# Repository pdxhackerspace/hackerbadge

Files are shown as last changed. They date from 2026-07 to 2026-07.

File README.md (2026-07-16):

# PDX Hackerspace Hackerbadge





The unofficial badge of PDX Hackerspace.

- 37 WS2812B addressable RGB LEDs
- SeeedStudio Xiao ESP32-S3 (8MB PSRAM/8MB flash)
- LSM6DSO accelerometer/gyroscope
- 18650 LiPO battery
- Qwiic/STEMMA QT I2C connector

Though we've specced this for a Xiao ESP32-S3, this should work with any Xiao board with a compatible pinout. If the board doesn't support LiPO battery charging then obviously it will only work when plugged into USB.

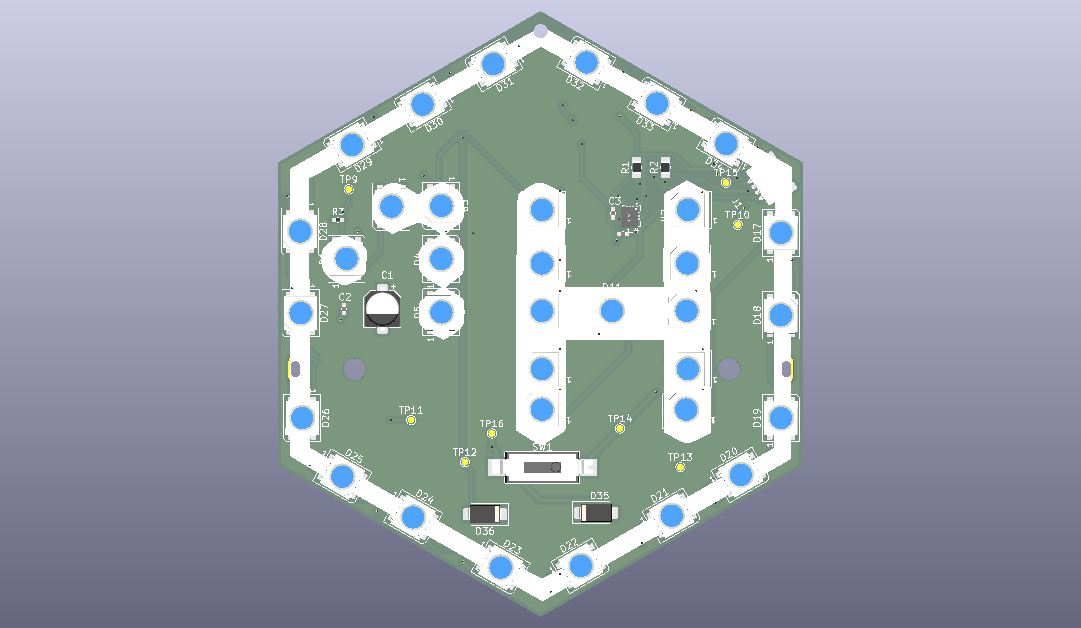
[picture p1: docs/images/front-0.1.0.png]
front
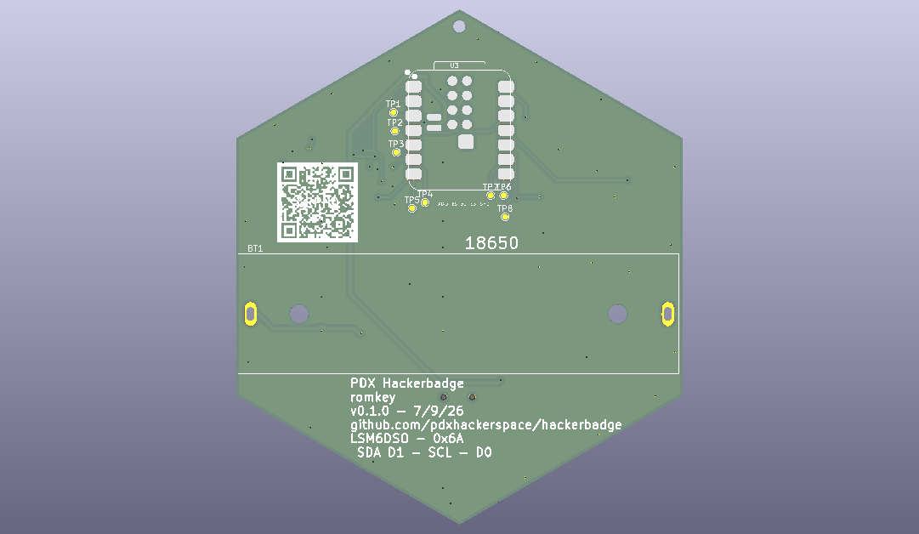
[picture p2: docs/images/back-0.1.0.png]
back
 

## LED power

LEDs are powered either through the VBUS or VBAT, avoiding straining the board's 3.3V regulator and providing more voltage to them for more reliable operation. We use two SS23 Schottky diodes to OR the power sources together and avoid feeding back into one another.

## LED control

Xiao ESP32-S3 D10 controls the LEDs.

## Qwiic/STEMMA QT/I2C

SDA - D1
SCL - D0

## Accelerometer/Gyroscope

The board includes an LSM6DSO accelerometer/gyroscope for fancy effects, or you can just ignore it. I2C address 0x6A.

## Firmware

Hardware self-test sketches live under `firmware/test/`. They cycle LED colors/patterns and exercise the LSM6DSO. Production-style options (WLED, ESPHome, CircuitPython) are below.

### WLED

1. Hold the Xiao **BOOT** button, plug in USB, then release BOOT so the board is in download mode.
2. Open the [WLED web installer](https://install.wled.me/) (or [alternate installer](https://wled-install.github.io/)) in Chrome/Edge.
3. Choose an **ESP32-S3** build that matches this board: **8MB flash** and **PSRAM** (OPI / `qio_opi` style binaries are the usual fit for the Xiao ESP32-S3). Flash it.
4. Join Wi‑Fi AP `WLED-AP` (password `wled1234`) and open [http://4.3.2.1](http://4.3.2.1).
5. **Config → LED Preferences** and set:
   - LED count / length: **37**
   - GPIO / data pin: **9** (Xiao **D10**)
   - LED type: **WS281x**
   - Color order: **GRB**
6. Save, then optionally configure your home Wi‑Fi under **Config → WiFi Setup**.

Stock WLED does not use the LSM6DSO.

**Docker Compose** (build a badge-tuned binary with GPIO 9 / 37 LEDs preconfigured):

```bash
cd firmware/wled
docker compose run --rm build
```

Firmware ends up under `firmware/wled/build/`. Flash with the web installer, `esptool`, or:

```bash
DEVICE=/dev/ttyACM0 docker compose run --rm --device=$DEVICE build upload
```

If the OPI-PSRAM build won’t boot, try `PIO_ENV=hackerbadge_qspi docker compose run --rm build`. See also [Compiling WLED](https://kno.wled.ge/advanced/compiling-wled/).

### ESPHome

Test config: `firmware/test/esphome/badge_test.yaml`

Requires an ESPHome release with the `motion` / `lsm6ds` platform. After flash, the badge cycles LED effects and logs IMU samples over serial. It also brings up AP `Hackerbadge-Test` (password `hackerspace`); open [http://192.168.4.1](http://192.168.4.1) for the web UI.

**Docker Compose** (dashboard on [http://localhost:6052](http://localhost:6052)):

```bash
cd firmware/test/esphome
docker compose up
```

Compile only, or compile and flash over USB:

```bash
docker compose run --rm esphome compile badge_test.yaml
DEVICE=/dev/ttyACM0 docker compose run --rm --device=$DEVICE esphome run badge_test.yaml
```

Without Docker: `esphome run firmware/test/esphome/badge_test.yaml`

### CircuitPython

Test program: `firmware/test/circuitpython/code.py`

1. Install [CircuitPython for Seeed Xiao ESP32-S3](https://circuitpython.org/board/seeed_xiao_esp32s3/).
2. From the [Adafruit library bundle](https://circuitpython.org/libraries), copy into `CIRCUITPY/lib/`:
   - `neopixel.mpy` (and `adafruit_pixelbuf.mpy` if present in your bundle)
   - `adafruit_lsm6ds/`
   - `adafruit_bus_device/`
   - `adafruit_register/`
3. Copy `firmware/test/circuitpython/code.py` to `CIRCUITPY/code.py`.

Watch the serial REPL for IMU logs while LEDs cycle.

### Arduino

Test sketch: `firmware/test/arduino/badge_test/badge_test.ino`

**Docker Compose** (Arduino CLI build; artifacts in `firmware/test/arduino/build/`):

```bash
cd firmware/test/arduino
docker compose run --rm build
```

Upload over USB after a successful compile:

```bash
DEVICE=/dev/ttyACM0 docker compose run --rm --device=$DEVICE build upload
```

Without Docker:

1. In Arduino IDE, install board support for **Seeed XIAO ESP32S3**.
2. Install libraries: **FastLED**, **Adafruit LSM6DS** (pulls in BusIO and Unified Sensor).
3. Open the `badge_test` sketch, select the Xiao ESP32S3 board/port, and upload.

Serial Monitor at 115200 baud shows effect names and IMU readings.

## Assembly

The badge comes prebuilt except for the Xiao and the battery holder, which are mounted on the back of the board. We suggest soldering on the Xiao using solder paste and a hot air gun. You're unlikely to make a solder plate work due to the components on the front of the board. The most difficult part will be the battery connectors under the board.

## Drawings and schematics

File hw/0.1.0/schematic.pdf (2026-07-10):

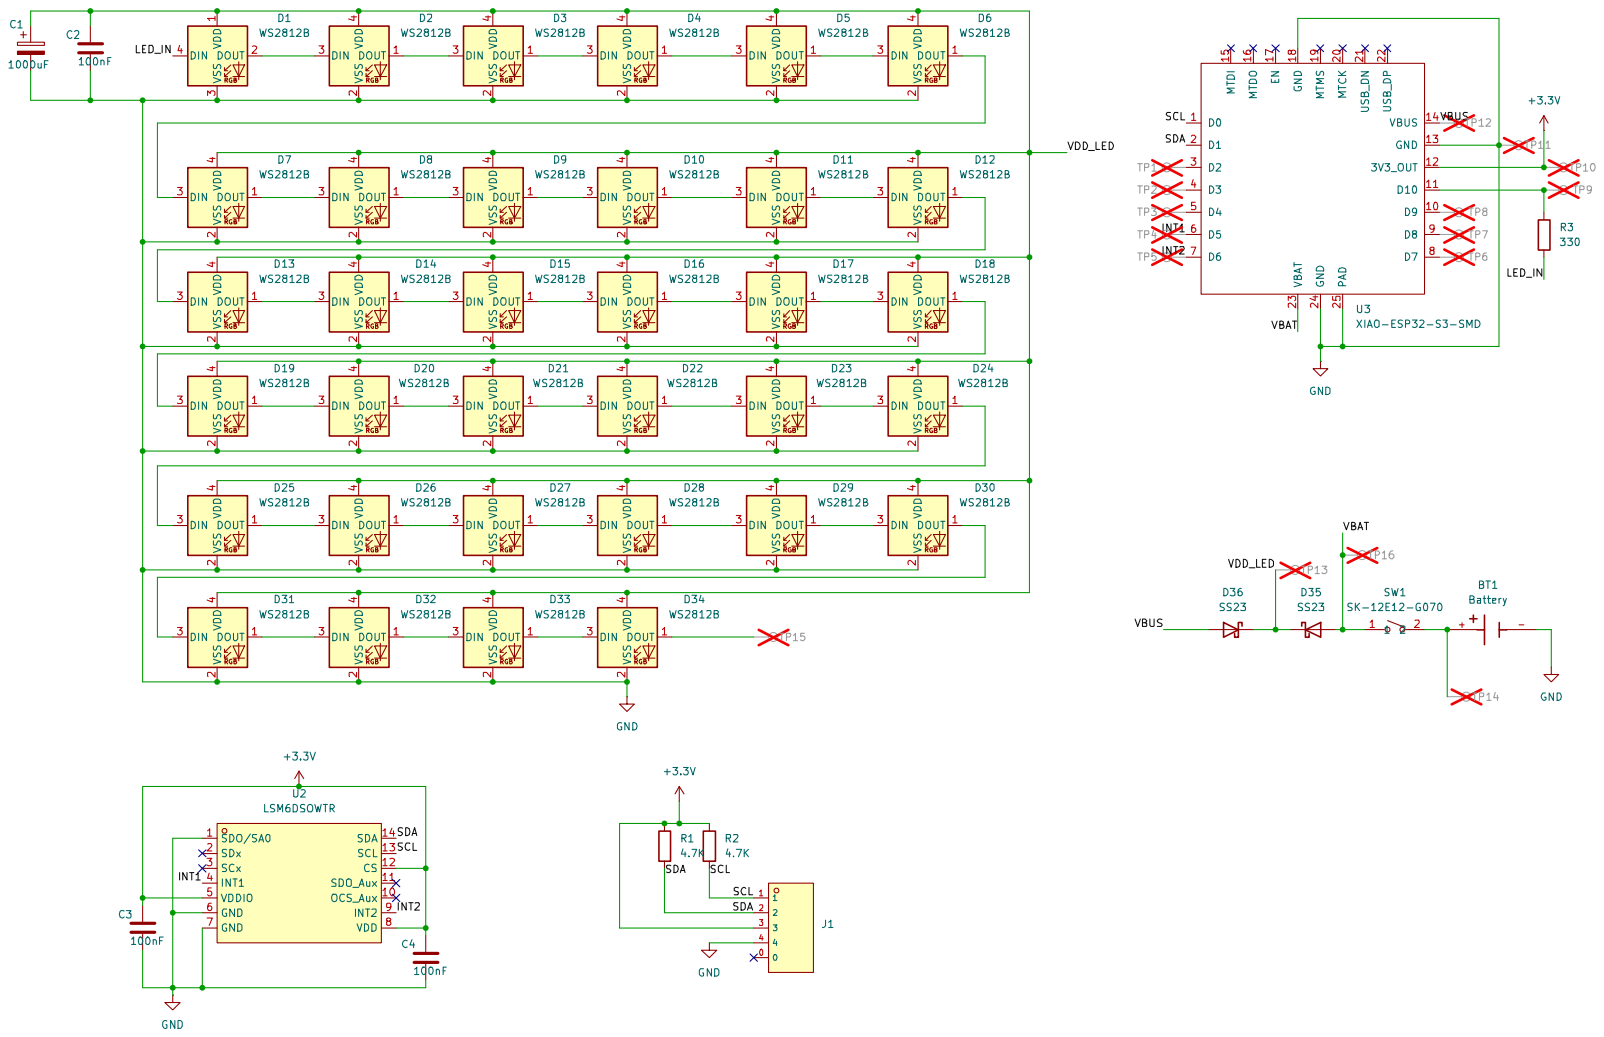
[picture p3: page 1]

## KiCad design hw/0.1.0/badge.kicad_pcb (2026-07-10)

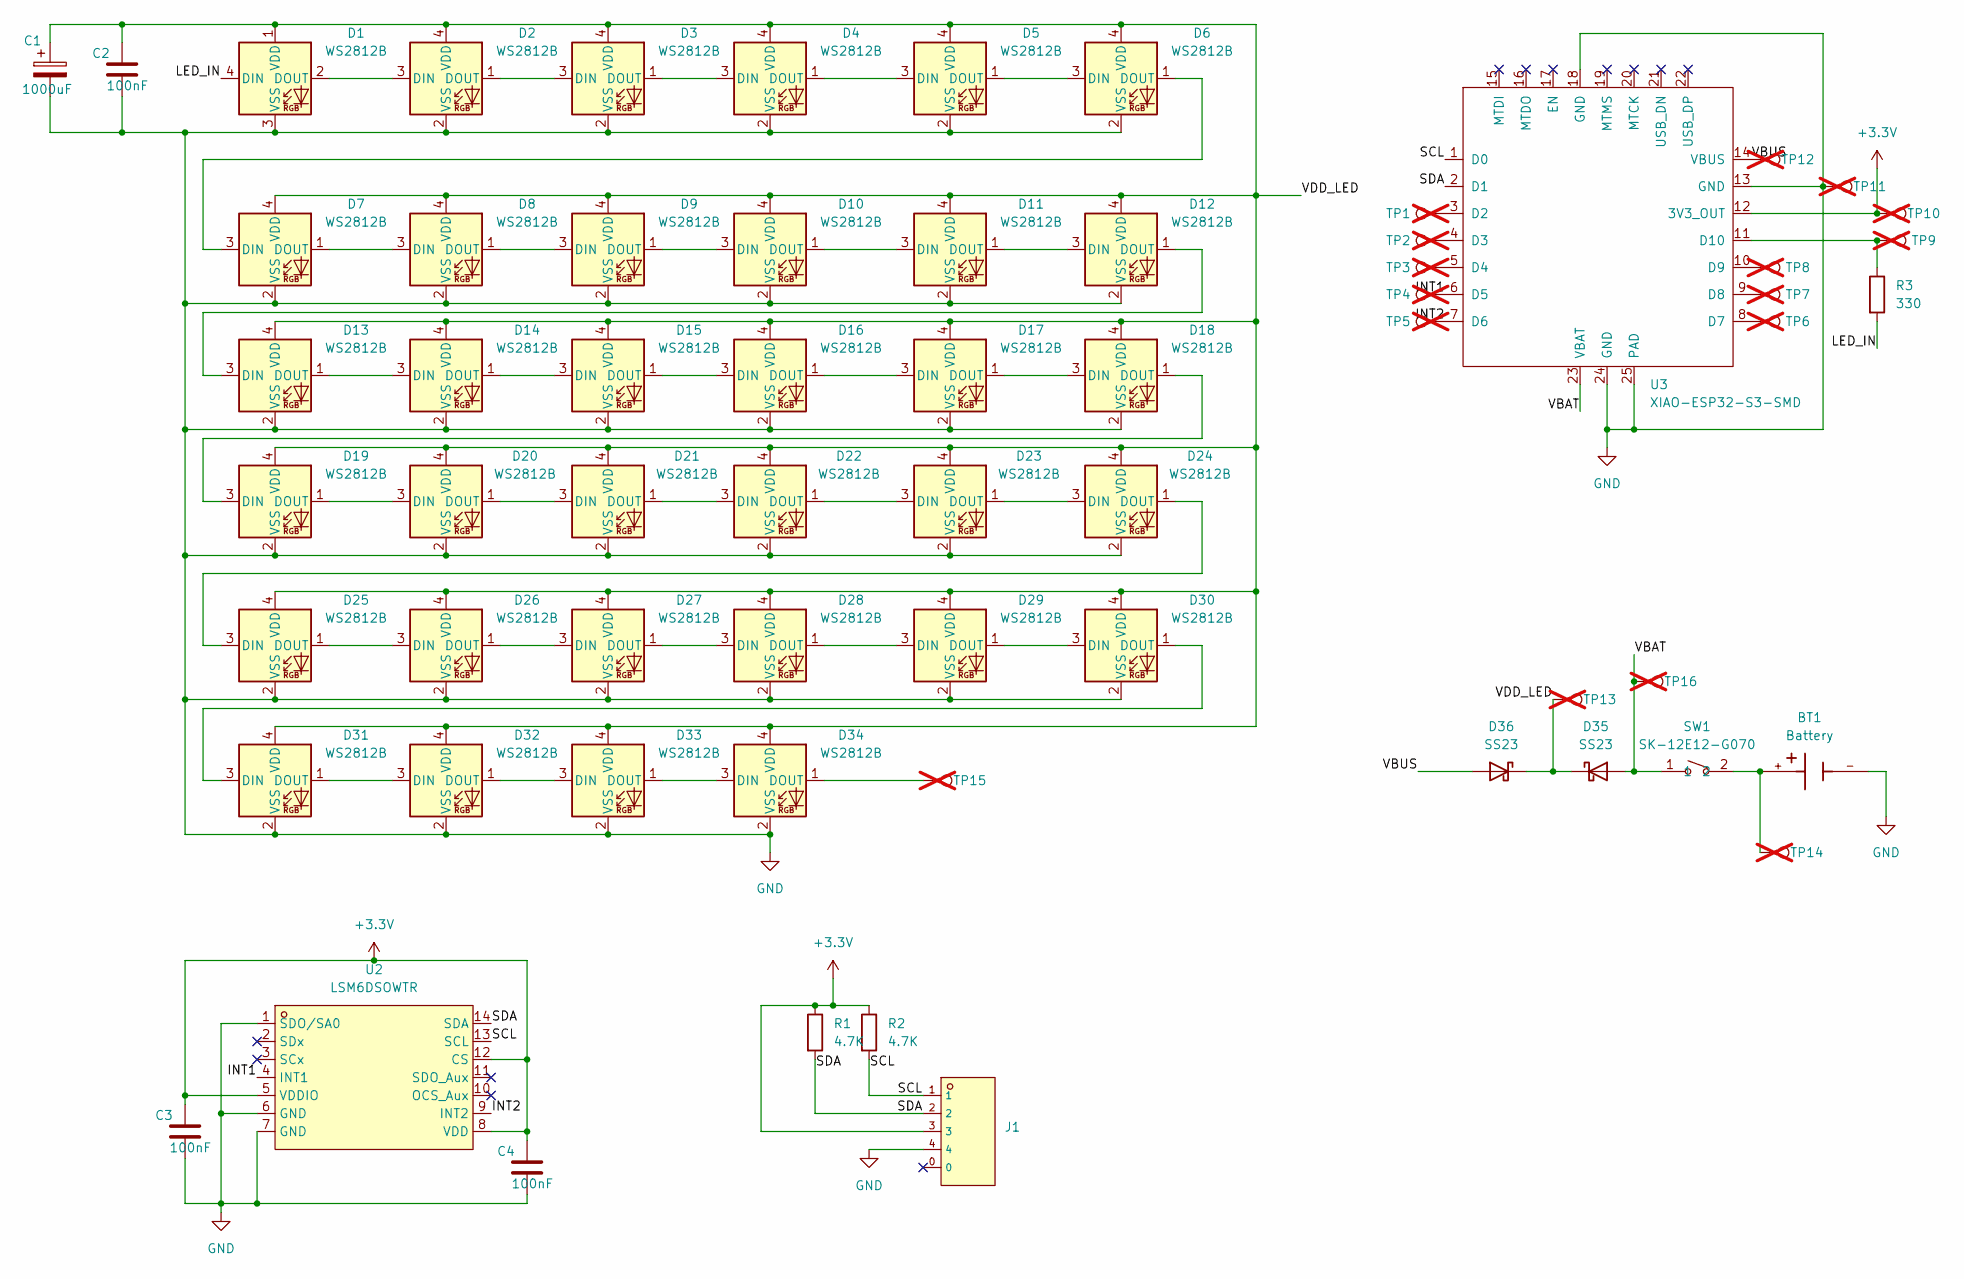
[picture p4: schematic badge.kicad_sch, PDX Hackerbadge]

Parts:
BT1: Battery; BAT_BK-18650-PC2; PARTREV F
C1: 1000uF; CP_Elec_5x5.4; MPN C3337
C2, C3, C4: 100nF; C_0402_1005Metric_Pad0.74x0.62mm_HandSolder; MPN C1523
D1, D2, D3, D4, D5, D6, D7, D8, D9, D10, D11, D12, D13, D14, D15, D16, D17, D18, D19, D20, D21, D22, D23, D24, D25, D26, D27, D28, D29, D30, D31, D32, D33, D34: WS2812B; LED_WS2812B_PLCC4_5.0x5.0mm_P3.2mm; MPN C52917433
D35, D36: SS23; D_SMA; MPN C232851
J1: CONN-SMD_4P-P1.00_SM04B-SRSS-TB-LF-SN; MPN C160404; LCSC C160390
R1, R2: 4.7K; R_0805_2012Metric_Pad1.20x1.40mm_HandSolder; MPN C105427
R3: 330; R_0402_1005Metric_Pad0.72x0.64mm_HandSolder; MPN C25104
SW1: SK-12E12-G070; SW-TH_MS-12D08G3.5; LCSC Part C2939255
TP1: D2; TestPoint_Pad_D1.0mm; not fitted
TP2: D3; TestPoint_Pad_D1.0mm; not fitted
TP3: D4; TestPoint_Pad_D1.0mm; not fitted
TP4: D5; TestPoint_Pad_D1.0mm; not fitted
TP5: INT2; TestPoint_Pad_D1.0mm; not fitted
TP6: D7; TestPoint_Pad_D1.0mm; not fitted
TP7: D8; TestPoint_Pad_D1.0mm; not fitted
TP8: D9; TestPoint_Pad_D1.0mm; not fitted
TP9: D10; TestPoint_Pad_D1.0mm; not fitted
TP10: 3V3; TestPoint_Pad_D1.0mm; not fitted
TP11: GND; TestPoint_Pad_D1.0mm; not fitted
TP12: VBUS; TestPoint_Pad_D1.0mm; not fitted
TP13: VDD_LED; TestPoint_Pad_D1.0mm; not fitted
TP14: RAWBAT; TestPoint_Pad_D1.0mm; not fitted
TP15: D34 DOUT; TestPoint_Pad_D1.0mm; not fitted
TP16: VBAT; TestPoint_Pad_D1.0mm; not fitted
U2: LSM6DSOWTR; LGA-14L_L3.0-W2.5-P0.50-TL; MPN C2829074; LCSC Part C2829074
U3: XIAO-ESP32-S3-SMD

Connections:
+3.3V: C3.1, C4.1, J1.3, R1.1, R2.1, TP10.1 (1_1), U2.5 (VDDIO), U2.8 (VDD), U2.12 (CS), U3.12 (3V3_OUT)
/INT1: TP4.1 (1_1), U2.4 (INT1), U3.6 (D5)
/INT2: TP5.1 (1_1), U2.9 (INT2), U3.7 (D6)
/LED_IN: D1.4 (DIN), R3.2
/SCL: J1.1, R2.2, U2.13 (SCL), U3.1 (D0)
/SDA: J1.2, R1.2, U2.14 (SDA), U3.2 (D1)
/VBAT: D35.2 (A), SW1.1, TP16.1 (1_1), U3.23 (VBAT)
/VBUS: D36.2 (A), TP12.1 (1_1), U3.14 (VBUS)
/VDD_LED: C1.1, C2.1, D1.1 (VDD), D2.4 (VDD), D3.4 (VDD), D4.4 (VDD), D5.4 (VDD), D6.4 (VDD), D7.4 (VDD), D8.4 (VDD), D9.4 (VDD), D10.4 (VDD), D11.4 (VDD), D12.4 (VDD), D13.4 (VDD), D14.4 (VDD), D15.4 (VDD), D16.4 (VDD), D17.4 (VDD), D18.4 (VDD), D19.4 (VDD), D20.4 (VDD), D21.4 (VDD), D22.4 (VDD), D23.4 (VDD), D24.4 (VDD), D25.4 (VDD), D26.4 (VDD), D27.4 (VDD), D28.4 (VDD), D29.4 (VDD), D30.4 (VDD), D31.4 (VDD), D32.4 (VDD), D33.4 (VDD), D34.4 (VDD), D35.1 (K), D36.1 (K), TP13.1 (1_1)
GND: BT1.-, C1.2, C2.2, C3.2, C4.2, D1.3 (VSS), D2.2 (VSS), D3.2 (VSS), D4.2 (VSS), D5.2 (VSS), D6.2 (VSS), D7.2 (VSS), D8.2 (VSS), D9.2 (VSS), D10.2 (VSS), D11.2 (VSS), D12.2 (VSS), D13.2 (VSS), D14.2 (VSS), D15.2 (VSS), D16.2 (VSS), D17.2 (VSS), D18.2 (VSS), D19.2 (VSS), D20.2 (VSS), D21.2 (VSS), D22.2 (VSS), D23.2 (VSS), D24.2 (VSS), D25.2 (VSS), D26.2 (VSS), D27.2 (VSS), D28.2 (VSS), D29.2 (VSS), D30.2 (VSS), D31.2 (VSS), D32.2 (VSS), D33.2 (VSS), D34.2 (VSS), J1.4, TP11.1 (1_1), U2.1 (SDO/SA0), U2.6 (GND), U2.7 (GND), U3.13 (GND), U3.18 (GND), U3.24 (GND), U3.25 (PAD)
unnamed: BT1.+, SW1.2, TP14.1 (1_1)
unnamed: D1.2 (DOUT), D2.3 (DIN)
unnamed: D2.1 (DOUT), D3.3 (DIN)
unnamed: D3.1 (DOUT), D4.3 (DIN)
unnamed: D4.1 (DOUT), D5.3 (DIN)
unnamed: D5.1 (DOUT), D6.3 (DIN)
unnamed: D6.1 (DOUT), D7.3 (DIN)
unnamed: D7.1 (DOUT), D8.3 (DIN)
unnamed: D8.1 (DOUT), D9.3 (DIN)
unnamed: D9.1 (DOUT), D10.3 (DIN)
unnamed: D10.1 (DOUT), D11.3 (DIN)
unnamed: D11.1 (DOUT), D12.3 (DIN)
unnamed: D12.1 (DOUT), D13.3 (DIN)
unnamed: D13.1 (DOUT), D14.3 (DIN)
unnamed: D14.1 (DOUT), D15.3 (DIN)
unnamed: D15.1 (DOUT), D16.3 (DIN)
unnamed: D16.1 (DOUT), D17.3 (DIN)
unnamed: D17.1 (DOUT), D18.3 (DIN)
unnamed: D18.1 (DOUT), D19.3 (DIN)
unnamed: D19.1 (DOUT), D20.3 (DIN)
unnamed: D20.1 (DOUT), D21.3 (DIN)
unnamed: D21.1 (DOUT), D22.3 (DIN)
unnamed: D22.1 (DOUT), D23.3 (DIN)
unnamed: D23.1 (DOUT), D24.3 (DIN)
unnamed: D24.1 (DOUT), D25.3 (DIN)
unnamed: D25.1 (DOUT), D26.3 (DIN)
unnamed: D26.1 (DOUT), D27.3 (DIN)
unnamed: D27.1 (DOUT), D28.3 (DIN)
unnamed: D28.1 (DOUT), D29.3 (DIN)
unnamed: D29.1 (DOUT), D30.3 (DIN)
unnamed: D30.1 (DOUT), D31.3 (DIN)
unnamed: D31.1 (DOUT), D32.3 (DIN)
unnamed: D32.1 (DOUT), D33.3 (DIN)
unnamed: D33.1 (DOUT), D34.3 (DIN)
unnamed: D34.1 (DOUT), TP15.1 (1_1)
unnamed: TP1.1 (1_1), U3.3 (D2)
unnamed: TP2.1 (1_1), U3.4 (D3)
unnamed: TP3.1 (1_1), U3.5 (D4)
unnamed: TP6.1 (1_1), U3.8 (D7)
unnamed: TP7.1 (1_1), U3.9 (D8)
unnamed: TP8.1 (1_1), U3.10 (D9)
unnamed: R3.1, TP9.1 (1_1), U3.11 (D10)

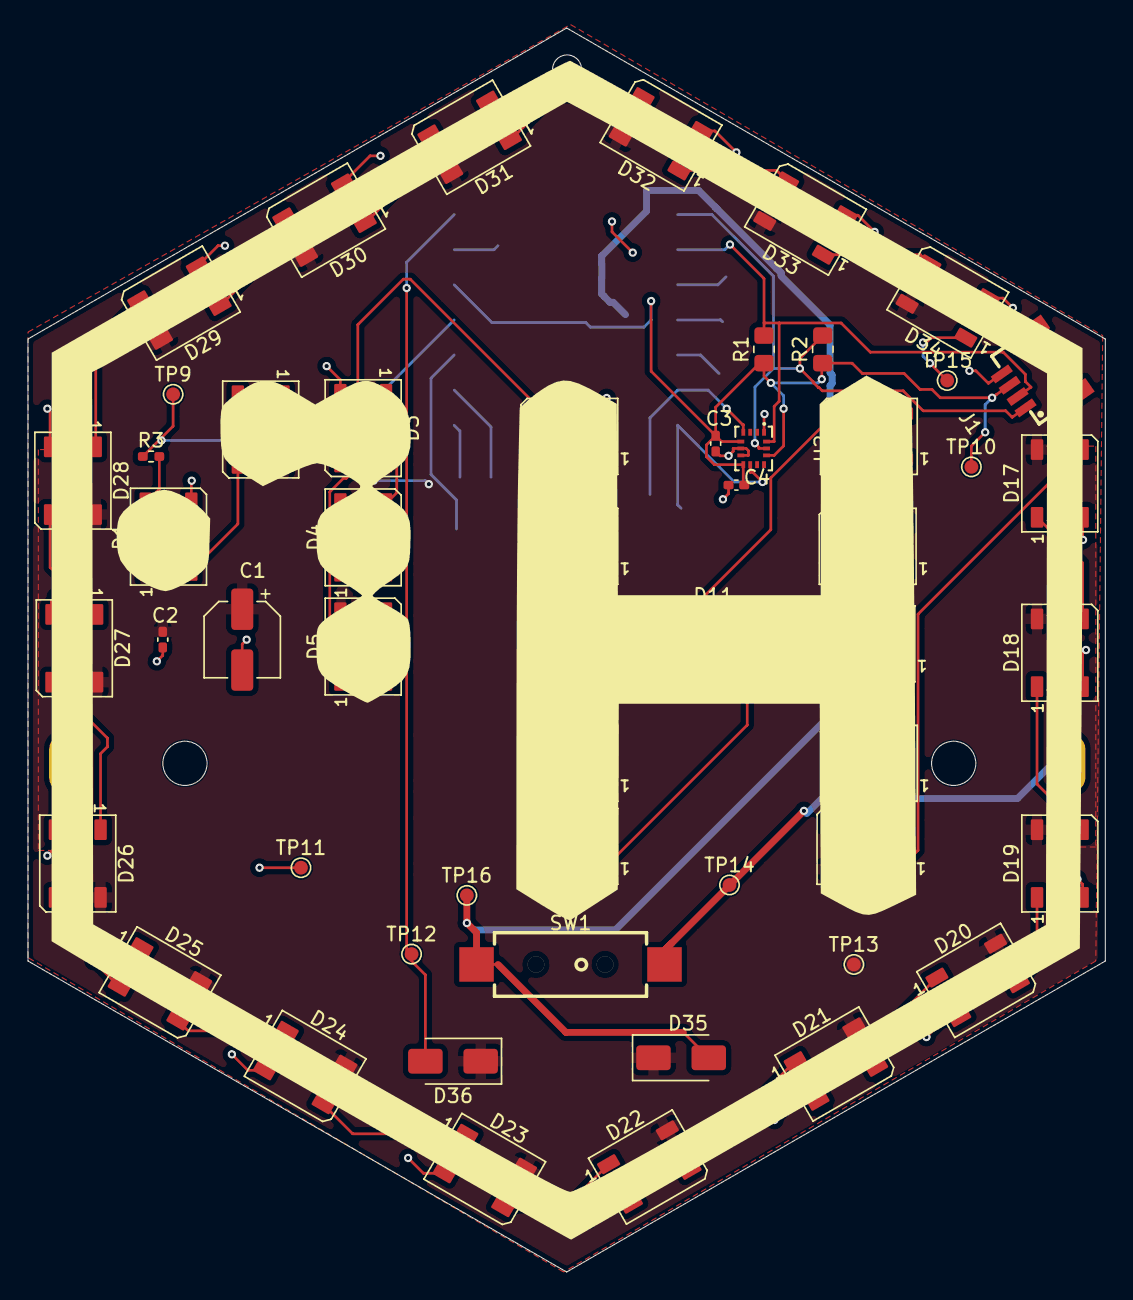
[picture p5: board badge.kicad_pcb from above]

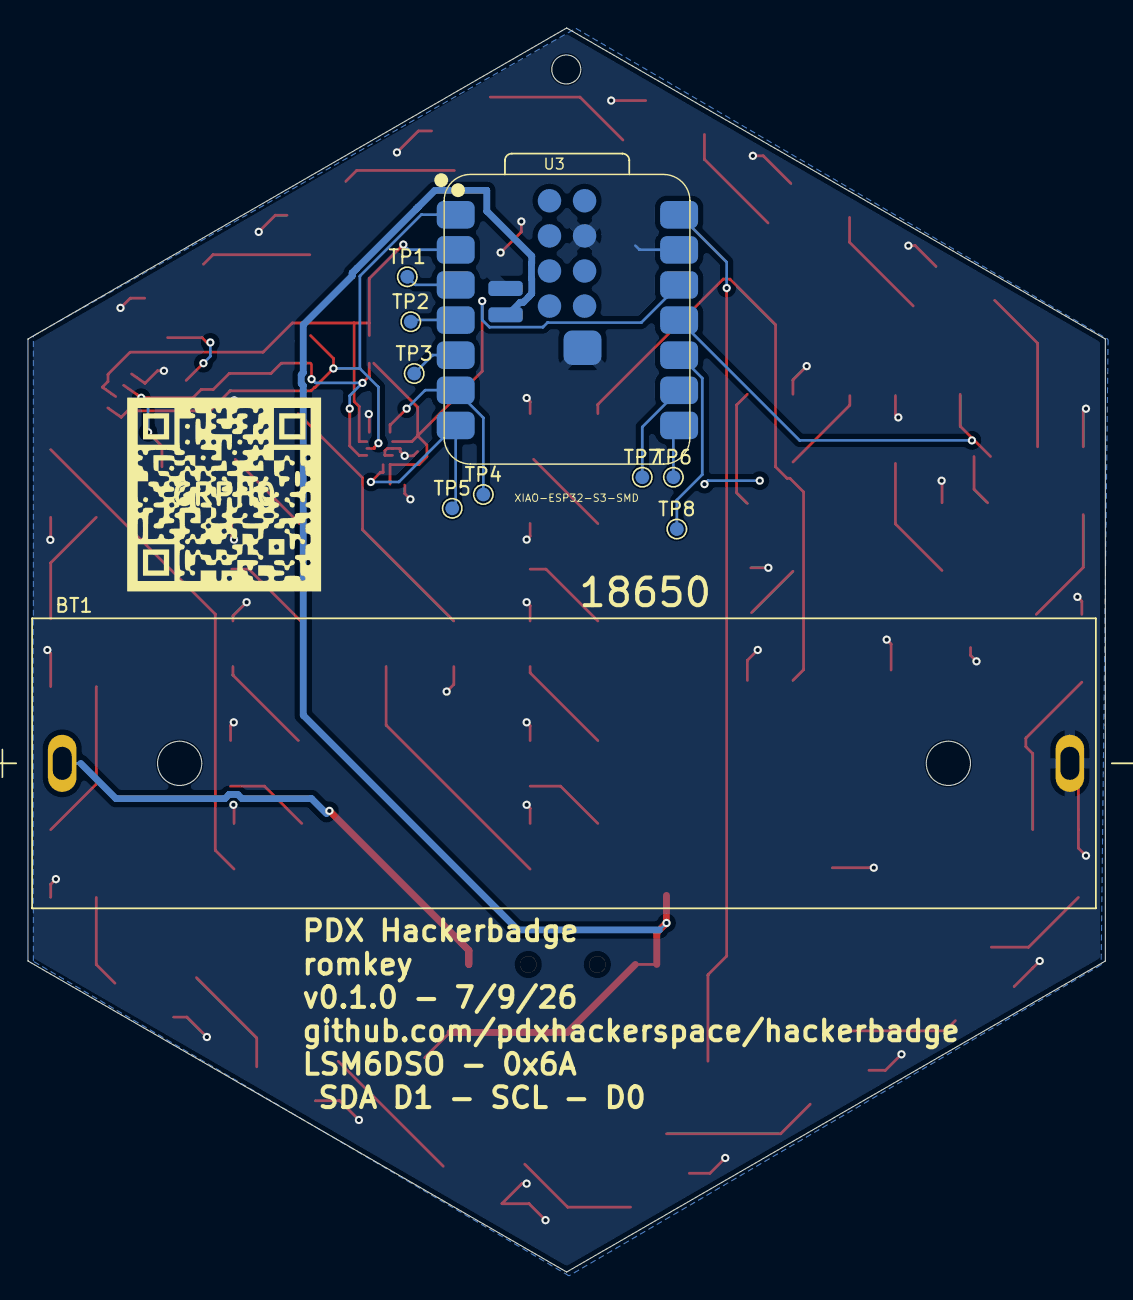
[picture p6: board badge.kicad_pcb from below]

Board: 2 copper layers, 77.9 x 90.0 mm, 66 parts (11 on the bottom side), 52 nets.

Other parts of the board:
GRPH0: LOGO
MNT0: MountingHole_2.1mm

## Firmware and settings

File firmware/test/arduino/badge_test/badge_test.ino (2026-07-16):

/*
 * PDX Hackerspace Hackerbadge — Arduino / FastLED hardware test
 *
 * Exercises the 37 WS2812B LEDs (colors + patterns) and the LSM6DSO IMU.
 *
 * Pinout (Seeed Xiao ESP32-S3):
 *   LED data  D10 = GPIO9
 *   I2C SDA   D1  = GPIO2
 *   I2C SCL   D0  = GPIO1
 *   LSM6DSO   0x6A
 *
 * Board:  Seeed XIAO ESP32S3
 * Libraries (Library Manager):
 *   - FastLED
 *   - Adafruit LSM6DS
 *   - Adafruit Unified Sensor  (dependency)
 *   - Adafruit BusIO           (dependency)
 *
 * After boot the badge cycles solid colors and patterns. Serial logs print
 * accel/gyro samples. The Accel Tilt effect maps orientation to LEDs.
 */

#include <Wire.h>
#include <FastLED.h>
#include <Adafruit_LSM6DSOX.h>
#include <Adafruit_Sensor.h>
#include <math.h>

#if defined(ARDUINO_XIAO_ESP32S3) || defined(ARDUINO_SEEED_XIAO_ESP32S3)
#define LED_DATA_PIN D10
#define I2C_SDA_PIN D1
#define I2C_SCL_PIN D0
#else
// Xiao ESP32-S3 GPIO map when using a generic ESP32-S3 board package
#define LED_DATA_PIN 9
#define I2C_SDA_PIN 2
#define I2C_SCL_PIN 1
#endif

#define NUM_LEDS 37
#define BRIGHTNESS 102  // ~40% of 255
#define EFFECT_MS 8000
#define IMU_LOG_MS 2000
#define FRAME_MS 40

CRGB leds[NUM_LEDS];
Adafruit_LSM6DSOX imu;
bool imuOk = false;
uint32_t lastImuLogMs = 0;

static float clampf(float v, float lo, float hi) {
  if (v < lo) return lo;
  if (v > hi) return hi;
  return v;
}

static void maybeLogImu(bool force = false) {
  uint32_t now = millis();
  if (!force && (now - lastImuLogMs) < IMU_LOG_MS) {
    return;
  }
  lastImuLogMs = now;

  if (!imuOk) {
    Serial.println(F("IMU: no accelerometer data (check I2C 0x6A)"));
    return;
  }

  sensors_event_t accel, gyro, temp;
  imu.getEvent(&accel, &gyro, &temp);

  Serial.printf(
      "IMU accel m/s2=(%.2f, %.2f, %.2f) gyro dps=(%.1f, %.1f, %.1f)\n",
      accel.acceleration.x, accel.acceleration.y, accel.acceleration.z,
      gyro.gyro.x * RAD_TO_DEG, gyro.gyro.y * RAD_TO_DEG,
      gyro.gyro.z * RAD_TO_DEG);
}

static void solid(const CRGB &color, uint32_t durationMs) {
  fill_solid(leds, NUM_LEDS, color);
  FastLED.show();
  uint32_t end = millis() + durationMs;
  while (millis() < end) {
    maybeLogImu();
    delay(50);
  }
}

static void rainbow(uint32_t durationMs) {
  uint32_t start = millis();
  uint8_t offset = 0;
  while (millis() - start < durationMs) {
    for (int i = 0; i < NUM_LEDS; i++) {
      leds[i] = CHSV(offset + (i * 255 / NUM_LEDS), 255, 255);
    }
    FastLED.show();
    offset += 4;
    maybeLogImu();
    delay(FRAME_MS);
  }
}

static void colorWipe(uint32_t durationMs) {
  const CRGB colors[] = {
      CRGB::Red, CRGB::Green, CRGB::Blue, CRGB::White,
  };
  uint32_t start = millis();
  while (millis() - start < durationMs) {
    for (CRGB color : colors) {
      for (int i = 0; i < NUM_LEDS; i++) {
        if (millis() - start >= durationMs) {
          return;
        }
        leds[i] = color;
        FastLED.show();
        maybeLogImu();
        delay(40);
      }
    }
  }
}

static void scan(uint32_t durationMs) {
  uint32_t start = millis();
  int pos = 0;
  int direction = 1;
  const int width = 3;
  while (millis() - start < durationMs) {
    fill_solid(leds, NUM_LEDS, CRGB::Black);
    for (int w = 0; w < width; w++) {
      int idx = pos + w;
      if (idx >= 0 && idx < NUM_LEDS) {
        leds[idx] = CRGB(0, 180, 255);
      }
    }
    FastLED.show();
    pos += direction;
    if (pos <= 0) {
      pos = 0;
      direction = 1;
    } else if (pos >= NUM_LEDS - width) {
      pos = NUM_LEDS - width;
      direction = -1;
    }
    maybeLogImu();
    delay(FRAME_MS);
  }
}

static void twinkle(uint32_t durationMs, bool randomColor) {
  uint32_t start = millis();
  uint8_t levels[NUM_LEDS] = {0};
  CRGB colors[NUM_LEDS];
  while (millis() - start < durationMs) {
    for (int i = 0; i < NUM_LEDS; i++) {
      if (levels[i] == 0 && random8() < 20) {  // ~8% of 255
        levels[i] = 255;
        colors[i] = randomColor ? CRGB(CHSV(random8(), 255, 255)) : CRGB::White;
      }
      if (levels[i] > 0) {
        leds[i] = colors[i];
        leds[i].nscale8(levels[i]);
        levels[i] = (levels[i] > 12) ? (levels[i] - 12) : 0;
      } else {
        leds[i] = CRGB::Black;
      }
    }
    FastLED.show();
    maybeLogImu();
    delay(FRAME_MS);
  }
}

static void fireworks(uint32_t durationMs) {
  uint32_t start = millis();
  uint8_t levels[NUM_LEDS] = {0};
  CRGB colors[NUM_LEDS];
  while (millis() - start < durationMs) {
    if (random8() < 30) {  // ~12%
      int i = random8(NUM_LEDS);
      levels[i] = 255;
      colors[i] = CHSV(random8(), 255, 255);
    }
    for (int i = 0; i < NUM_LEDS; i++) {
      if (levels[i] > 0) {
        leds[i] = colors[i];
        leds[i].nscale8(levels[i]);
        levels[i] = (levels[i] > 8) ? (levels[i] - 8) : 0;
      } else {
        leds[i] = CRGB::Black;
      }
    }
    FastLED.show();
    maybeLogImu();
    delay(FRAME_MS);
  }
}

static void accelTilt(uint32_t durationMs) {
  uint32_t start = millis();
  while (millis() - start < durationMs) {
    maybeLogImu();
    if (!imuOk) {
      fill_solid(leds, NUM_LEDS, CRGB(40, 0, 0));
      FastLED.show();
      delay(200);
      continue;
    }

    sensors_event_t accel, gyro, temp;
    imu.getEvent(&accel, &gyro, &temp);
    float ax = accel.acceleration.x;
    float ay = accel.acceleration.y;
    float az = accel.acceleration.z;

    float pitch = atan2f(-ax, sqrtf(ay * ay + az * az)) * RAD_TO_DEG;
    float roll = atan2f(ay, az) * RAD_TO_DEG;
    float pr = clampf((pitch + 45.0f) / 90.0f, 0.0f, 1.0f);
    float rr = clampf((roll + 45.0f) / 90.0f, 0.0f, 1.0f);

    uint8_t red = (uint8_t)(pr * 255.0f);
    uint8_t green = (uint8_t)(rr * 255.0f);
    uint8_t blue = (uint8_t)((1.0f - fabsf(pr - 0.5f) * 2.0f) * 80.0f);

    fill_solid(leds, NUM_LEDS, CRGB(red / 4, green / 4, blue / 4));
    int idx = (int)(rr * (NUM_LEDS - 1));
    leds[idx] = CRGB(red, green, 255);
    FastLED.show();
    delay(FRAME_MS);
  }
}

struct Effect {
  const char *name;
  void (*run)(uint32_t durationMs);
};

// Wrappers so twinkle variants fit the Effect table
static void twinkleWhite(uint32_t ms) { twinkle(ms, false); }
static void twinkleRandom(uint32_t ms) { twinkle(ms, true); }
static void solidRed(uint32_t ms) { solid(CRGB::Red, ms); }
static void solidGreen(uint32_t ms) { solid(CRGB::Green, ms); }
static void solidBlue(uint32_t ms) { solid(CRGB::Blue, ms); }
static void solidWhite(uint32_t ms) { solid(CRGB::White, ms); }
static void solidCyan(uint32_t ms) { solid(CRGB::Cyan, ms); }
static void solidMagenta(uint32_t ms) { solid(CRGB::Magenta, ms); }
static void solidYellow(uint32_t ms) { solid(CRGB::Yellow, ms); }

static const Effect EFFECTS[] = {
    {"Solid Red", solidRed},
    {"Solid Green", solidGreen},
    {"Solid Blue", solidBlue},
    {"Solid White", solidWhite},
    {"Solid Cyan", solidCyan},
    {"Solid Magenta", solidMagenta},
    {"Solid Yellow", solidYellow},
    {"Rainbow", rainbow},
    {"Color Wipe", colorWipe},
    {"Scan", scan},
    {"Twinkle", twinkleWhite},
    {"Random Twinkle", twinkleRandom},
    {"Fireworks", fireworks},
    {"Accel Tilt", accelTilt},
};

void setup() {
  Serial.begin(115200);
  delay(500);
  Serial.println(F("Hackerbadge test starting — LED pattern loop + IMU"));

  FastLED.addLeds<WS2812B, LED_DATA_PIN, GRB>(leds, NUM_LEDS);
  FastLED.setBrightness(BRIGHTNESS);
  FastLED.clear(true);

  // Badge I2C is on D0/D1, not the Xiao default SDA/SCL pads.
  Wire.begin(I2C_SDA_PIN, I2C_SCL_PIN);

  imuOk = imu.begin_I2C(0x6A, &Wire);
  if (imuOk) {
    imu.setAccelRange(LSM6DS_ACCEL_RANGE_4_G);
    imu.setGyroRange(LSM6DS_GYRO_RANGE_2000_DPS);
    imu.setAccelDataRate(LSM6DS_RATE_104_HZ);
    imu.setGyroDataRate(LSM6DS_RATE_104_HZ);
    Serial.println(F("IMU: LSM6DSO ready at 0x6A"));
  } else {
    Serial.println(F("IMU: init failed — check wiring / I2C pullups; LED tests will still run"));
  }

  maybeLogImu(true);
}

void loop() {
  for (const Effect &effect : EFFECTS) {
    Serial.print(F("LED effect -> "));
    Serial.println(effect.name);
    effect.run(EFFECT_MS);
  }
}

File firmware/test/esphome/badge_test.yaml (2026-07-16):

# PDX Hackerspace Hackerbadge — ESPHome hardware test
#
# Exercises the 37 WS2812B LEDs (colors + patterns) and the LSM6DSO IMU.
#
# Pinout (Seeed Xiao ESP32-S3):
#   LED data  D10 = GPIO9
#   I2C SDA   D1  = GPIO2
#   I2C SCL   D0  = GPIO1
#   LSM6DSO   0x6A
#
# Flash:
#   esphome run firmware/test/esphome/badge_test.yaml
#
# After boot the badge cycles solid colors and addressable patterns. Serial
# logs print accel/gyro samples; join Wi‑Fi AP "Hackerbadge-Test" (password
# hackerspace) and open http://192.168.4.1/ for live sensor values.
#
# Requires ESPHome with the motion/lsm6ds platform (LSM6DSO support).

substitutions:
  name: hackerbadge-test
  friendly_name: Hackerbadge Test

esphome:
  name: ${name}
  friendly_name: ${friendly_name}
  on_boot:
    priority: -100
    then:
      - logger.log: "Hackerbadge test starting — LED pattern loop + IMU"
      - light.turn_on:
          id: badge_leds
          brightness: 40%
          effect: Solid Red

esp32:
  board: seeed_xiao_esp32s3
  framework:
    type: arduino

packages:
  wifi-diagnostics: github://romkey/esphome-lib/lib/wifi-diagnostics.yml@main
  esp32-diagnostics: github://romkey/esphome-lib/lib/esp32.yml@main
  i2c-scan: github://romkey/esphome-lib/lib/i2c-scan.yml@main
  restart: github://romkey/esphome-lib/lib/restart.yml@main

logger:
  level: INFO

# Standalone test AP — no Home Assistant / secrets required
wifi:
  ap:
    ssid: "Hackerbadge-Test"
    password: "hackerspace"

api:

captive_portal:

web_server:
  port: 80

# --- I2C: Qwiic/STEMMA QT + onboard LSM6DSO ---
i2c:
  id: i2c0  # required by the i2c-scan package
  sda: GPIO2  # D1
  scl: GPIO1  # D0
  scan: true
  frequency: 400kHz

motion:
  - platform: lsm6ds
    id: badge_imu
    address: 0x6A
    accelerometer_range: 4G
    gyroscope_range: 2000DPS
    update_interval: 100ms

sensor:
  - platform: motion
    type: acceleration_x
    name: "Accel X"
    id: accel_x
  - platform: motion
    type: acceleration_y
    name: "Accel Y"
    id: accel_y
  - platform: motion
    type: acceleration_z
    name: "Accel Z"
    id: accel_z
  - platform: motion
    type: gyroscope_x
    name: "Gyro X"
    id: gyro_x
  - platform: motion
    type: gyroscope_y
    name: "Gyro Y"
    id: gyro_y
  - platform: motion
    type: gyroscope_z
    name: "Gyro Z"
    id: gyro_z
  - platform: motion
    type: pitch
    name: "Pitch"
    id: pitch
  - platform: motion
    type: roll
    name: "Roll"
    id: roll

# --- 37 WS2812B on D10 ---
light:
  - platform: esp32_rmt_led_strip
    id: badge_leds
    name: "Badge LEDs"
    pin: GPIO9  # D10
    num_leds: 37
    chipset: ws2812
    rgb_order: GRB
    default_transition_length: 0s
    effects:
      - addressable_lambda:
          name: Solid Red
          update_interval: 500ms
          lambda: |-
            it.all() = Color(255, 0, 0);
      - addressable_lambda:
          name: Solid Green
          update_interval: 500ms
          lambda: |-
            it.all() = Color(0, 255, 0);
      - addressable_lambda:
          name: Solid Blue
          update_interval: 500ms
          lambda: |-
            it.all() = Color(0, 0, 255);
      - addressable_lambda:
          name: Solid White
          update_interval: 500ms
          lambda: |-
            it.all() = Color(255, 255, 255);
      - addressable_lambda:
          name: Solid Cyan
          update_interval: 500ms
          lambda: |-
            it.all() = Color(0, 255, 255);
      - addressable_lambda:
          name: Solid Magenta
          update_interval: 500ms
          lambda: |-
            it.all() = Color(255, 0, 255);
      - addressable_lambda:
          name: Solid Yellow
          update_interval: 500ms
          lambda: |-
            it.all() = Color(255, 255, 0);
      - addressable_rainbow:
          name: Rainbow
          speed: 20
          width: 37
      - addressable_color_wipe:
          name: Color Wipe
          colors:
            - red: 100%
              green: 0%
              blue: 0%
              num_leds: 8
            - red: 0%
              green: 100%
              blue: 0%
              num_leds: 8
            - red: 0%
              green: 0%
              blue: 100%
              num_leds: 8
            - red: 100%
              green: 100%
              blue: 100%
              num_leds: 8
          add_led_interval: 40ms
      - addressable_scan:
          name: Scan
          move_interval: 40ms
          scan_width: 3
      - addressable_twinkle:
          name: Twinkle
          twinkle_probability: 8%
          progress_interval: 16ms
      - addressable_random_twinkle:
          name: Random Twinkle
          twinkle_probability: 8%
          progress_interval: 32ms
      - addressable_fireworks:
          name: Fireworks
          update_interval: 32ms
          spark_probability: 12%
          use_random_color: true
          fade_out_rate: 120
      # Visual IMU check: LED color tracks pitch/roll; a bright dot follows tilt.
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

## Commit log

2026-07-10 added schematic, hopefully fixed images
2026-07-16 fix ESPHome CI failure
    [badge_test.yaml]
2026-07-16 added circuit python CI
    fixed speedups
2026-07-16 split out workflows for arduino, esphome, circuitpython and gave them separate badges
